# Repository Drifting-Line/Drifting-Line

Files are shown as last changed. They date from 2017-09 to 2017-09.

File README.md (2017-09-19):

# Drifting-Line
The current Mediterranean migratory crisis is causing a large number of deaths at sea: in 2016 more than 5,000 people died trying to reach Europe on board of overcrowded clandestine boats.
The relief panorama has distinct features and connotations: together with government and military naval units, a large number of NGOs has taken the field. International humanitarian treaties on refugees and asylum seekers are very clear and demand that the needs of human beings belonging from countries of war and persecution must be supported in the name of solidarity and common sense of brotherhood. It is time for the Union countries to align with these needs and seek stable and substantial solutions. Meanwhile, this emergency situation requires for the provision of search and rescue measures to avoid the deaths of a large number of desperate and troubled people. The project fits within this area as a concrete support to the existing reliefs network.

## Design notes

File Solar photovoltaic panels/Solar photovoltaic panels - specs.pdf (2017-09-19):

142

I pannelli solari costituiscono una scelta obbligata per quanto riguarda installazioni operative in mare in maniera autonoma e quindi anche nel caso di Drifting-Line.
I modelli da impiegare dovranno essere di piccole dimensioni, leggeri e impermeabili. Il materiale dovrà essere costituito da celle solari amorfe ad alta efficienza, resistenti ai raggi UV e al graffio: il silicio amorfo infatti è più performante in ambienti marittimi rispetto al monocristallino, dove l’umidità e la salsedine rischiano di intaccare maggiormente il materiale. L’attuale facilità di reperimento di tale tecnologia e le possibilità di customizzazione permetteranno di ottenere modelli realizzati assecondando le diverse esigenze e necessità.
Date la vicinanza alle coste nord-africane tali pannelli dovranno essere montati a bordo delle boe con un’inclinazione di 10° (in caso di riutilizzo del progetto in altre posizioni geografiche tale misura dovrà riadattarsi alle diverse latitudini); l’installazione di due pannelli simmetrici rispetto all’asse centrale di sostegno assicurerà maggiore potenza di ricarica ed eviterà, nonostante il peso contenuto, eventuali sbilanciamenti e squilibri.

Caratteristiche principali:
1. Tensione di circuito aperta: 7.7V
2. Tensione di picco: 6.5V
3. Corrente di picco: 340mA
4. Potenza di picco: 2.2W
5. Viti da integrare per un facile montaggio

### 4.2.2.7 Pannelli fotovoltaici

Dimensioni:
customizzabili
Peso:
100g ca.

solar
panels

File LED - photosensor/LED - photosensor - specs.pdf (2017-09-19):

141

In campo marittimo l’illuminazione è un fattore chiave per la sicurezza della navigazione in mare durante le ore notturne o in caso di scarsa visibilità. Come già spiegato precedentemente a bordo di un’imbarcazione ci possono essere vari strumenti che consentono di rilevare la presenza di altri natanti e boe di segnalazione: per esempio radar o tecnologia GPS. Una corretta illuminazione è tuttavia di fondamentale importanza, soprattutto in caso di maltempo o guasti delle strumentazioni di avvistamento.
La tecnologia LED ha consentito un notevole avanzamento per quanto riguarda il consumo della batteria: lasciare accese le luci di posizione per lunghi periodi all’interno di imbarcazioni o altre installazioni in mare non risulta più una preoccupazione come avveniva precedentemente con le lampade tradizionali. Esistono anche altri vantaggi che derivano dall’uso dell’illuminazione LED: tali dispositivi occupano poco spazio e consentono di ottimizzare la progettazione di apparecchi articolati come nel caso di Drifting-Line; in più il ciclo di vita è molto più lungo rispetto a quello delle lampadine tradizionali: ciò permette, in campo nautico e in caso di installazioni in mare, di ridurre al minimo i viaggi a scopo di manutenzione e sostituzione di componenti esauriti.
Per il progetto Drifting-Line verranno utilizzate le strisce LED: idonee per la realizzazione di molti progetti, sono flessibili e dotate di adesivi sul retro che permettono di attaccarle a differenti tipi di supporto. Verranno adoperate strisce impermeabili (ricoperte di silicone), adatte ad essere utlizzate in esterno.

Caratteristiche principali:
1. Alimentazione: DC 12V
2. Consumo per 5m: 72W
3. Luminosità: 6000Lm
4. Durata: 25.000h ca.
5. Temperatura di esercizio: da -20° a +60°
6. Bassissima emissione di calore
7. Altissima flessibilità
8. Striscia divisibile ogni 3 LED
9. Larghezza striscia: 10mm
10. A norma CE RoHS

Il fotosensore (più propriamente detto fotoresistore) è un dispositivo realizzato tramite sostanze sensibili alla luce. Il sensore sarà messo in comunicazione direttamente con il microprocessore di Arduino consentendo così l’accensione dei LED in caso di mancanza di luce, sia durante le ore notturne che in condizioni di maltempo e di scarsa visibilità.
Si tratta di dispositivi molto piccoli e economici: i valori in termini di costi, dimensioni e peso possono essere ritenuti trascurabili all’interno di tutte le voci del progetto.

### 4.2.2.5 Illuminazione LED

### 4.2.2.6 Fotosensore

Dimensioni (per bobina):
in commercio bobine da 5m
Peso (per bobina):
1kg ca.

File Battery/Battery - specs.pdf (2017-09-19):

135

Il litio (spesso abbreviato con Li-Ion) è uno dei principali materiali utilizzati in vari campi dell’elettronica. I vantaggi che derivano dal suo utilizzo nei sistemi di carica sono molteplici: è possibile realizzare batterie molto convenienti ed economiche che possono essere assemblate in diverse forme, raggiungere piccole dimensioni ed essere di gran lunga più leggere di altri modelli realizzati in differenti materiali. Si tratta di batterie in genere poco suscettibili ai cambiamenti di temperatura (per questo vengono largamente utilizzate nel campo della telefonia mobile e dei tablet), una caratteristica determinante per l’inserimento di tale materiale nel progetto in questione: l’esposizione continuata al sole dei dispositivi Drifting-Line ha comportato la scelta di un’alimentazione che non risultasse delicata e che fosse economica da sostituire in caso di anomalie o malfunzionamenti, rendendo così trascurabili alcune sue caratteristiche negative (come, per esempio, il degrado progressivo anche in casi di non utilizzo).

Si stima che la corrente necessaria per il sostentamento del sistema Drifting-Line ammonti a 100Ah: si tratta di un conteggio approssimativo di riferimento; per ottenere un risultato preciso è necessario svolgere dei calcoli per cui è indispensabile conoscere e ricavare, attraverso prove e verifiche, il consumo a riposo e in funzionamento di tutti i componenti del sistema (Arduino + Iridium 9603 + IMSI-Catcher + fotosensore, illuminazione LED), valori impossibili da ottenere a priori.
Un’altra variabile del calcolo di progettazione della batteria è il tempo di autonomia richiesto al dispositivo per funzionare autonomamente. Nel caso di Drifting-Line è stata ipotizzata una vita media di circa un anno e mezzo: si tratta di un buon compromesso temporale per mantenere bassi i volumi e i costi di progettazione della batteria e del sistema di ricarica (che come vedremo nelle pagine successive avviene attraverso tecnologia solare); il progetto non può rappresentare una soluzione duratura, infatti nel caso più specifico del fenomeno della crisi umanitaria si spera che un anno e mezzo possa corrispondere a un periodo di miglioramenti e cambiamenti in campo politico e governativo.

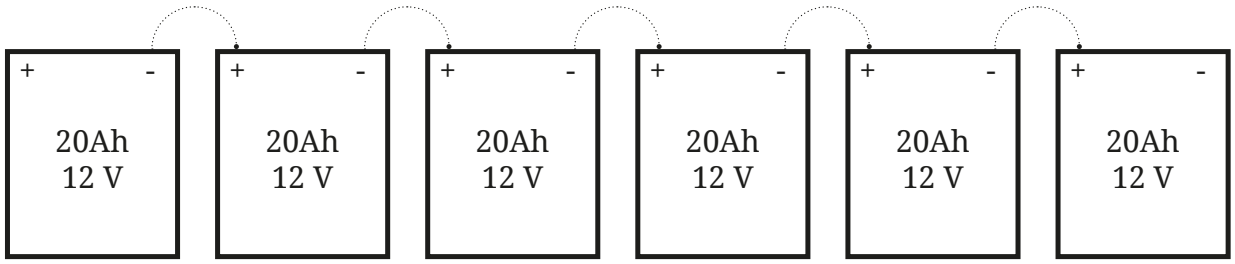
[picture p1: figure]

Il progetto prevede dunque l’utilizzo in serie di sei pack di batterie al litio da 20Ah ciascuna, in modo tale da garantire e superare il valore minimo definito precedentemente a 100Ah. In caso di anomalie e irregolarità un sistema ridondante può risultare favorevole: l’aumento e la suddivisione delle componenti di carica permette di accrescere l’affidabilità e la disponibilità durante tutto il tempo di funzionamento.

### 4.2.2.1 Batterie al litio 12v 20Ah

Dimensioni (per unità):
customizzabili
Peso (per unità):
2kg ca.

Progetto scaricabile da Github

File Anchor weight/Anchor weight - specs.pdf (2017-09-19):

146

La misurazione dell’ancoraggio prevede un calcolo specifico in cui le varibili di riferimento sono le forze dovute al vento e alle correnti.

Forze dovute al vento (FV)
Fv= 0,0128 · V² (nodi) · K
K= 1,3
Fv= 0,0128 · 60²
- 1,3= 60kgf/m²
Se si moltiplica tale risultato per il valore della superficie esterna della boa (S1

) si otteniene la misura delle forze di attrito del vento che incidono sulla boa stessa, ovvero:
FV= Fv (kgf/m²

) · S1 (m²

)
FV= 60 · 2,1= 126kgf

Forze dovute alle correnti (Fc)
Si dividono in due componenti: (Pd + Pf)
1. Pd è la spinta dinamica della corrente che investe la proiezione verticale della parte sommersa della boa:
Pd= 2,86 · Kd · S2 (m²

) · c²
Kd= 0,75 - 1
Pd= 2,86 · 1 · 1,8 · 0,6²

= 1,8kgf

2. Pf è la resistenza di attrito: Pf= Kf · S2 (m²

) · c²
Kf= 0,01
Pf= 0,01 · 1,8 · 0,6²

= 0,006kgf

Forze totali (Ftot)
Ftot= Fv + Fc
Ftot= 126 + 1,8 + 0,006= 127,8kgf

Il risultato ottenuto corrisponde alle somma delle forze che insistono sulla struttura di ciascuna boa. Il peso in acqua del carico che verrà gettato come ancoraggio sul fondale dovrà avere un valore maggiore per riuscire a contrastare in maniera efficace le spinte esterne.
Il progetto Drifting-Line prevede di utilizzare tre o più gabbie metalliche in acciaio zincato da riempire di materiale inerte (nel caso specifico tre gabbie metalliche da 40/50kg ciascuna) e collegate alla cima principale tramite altri tre segmenti di Dyneema® SK78 lunghi cinque metri ciascuno. Si potrà utilizzare calcestruzzo o semilavorati in metallo, pietre o materiale dismesso di qualsiasi genere; tutti i carichi gettati in acqua tuttavia perdono parte della loro forza peso ed è bene specificare già da subito che a parità di volume il metallo è l’elemento più adatto per queste condizioni.

## 4.2.5 Ancoraggio

Dati di partenza:
1. Velocità massima del vento (V): 60nodi
2. Superficie esterna di attrito della boa (S1

): 2,1m²
3. Velocità della corrente
(c): 0,6nodi
4. Superficie immersa di attrito della boa (S2

): 1,8m²

↑ Percentuale di peso
perso dai materiali in
acqua.

Valori dei pesi in → acqua di calcestruzzo

e acciaio, i materiali
di ancoraggio più
comunemente utilizzati.

Calcestruzzo
45%

Peso ancora

230kg
138kg
92kg
46kg
23kg
13kg

Csl

126kg
75kg
50kg
25kg
12kg
7kg

Acciaio

194kg
116kg
77kg
38kg
19kg
11kg

Granito
36%

Ferro
14%

Acciaio
13%

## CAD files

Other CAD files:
3D print components/#3D print.3dm

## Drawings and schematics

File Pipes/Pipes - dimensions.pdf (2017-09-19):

1

2

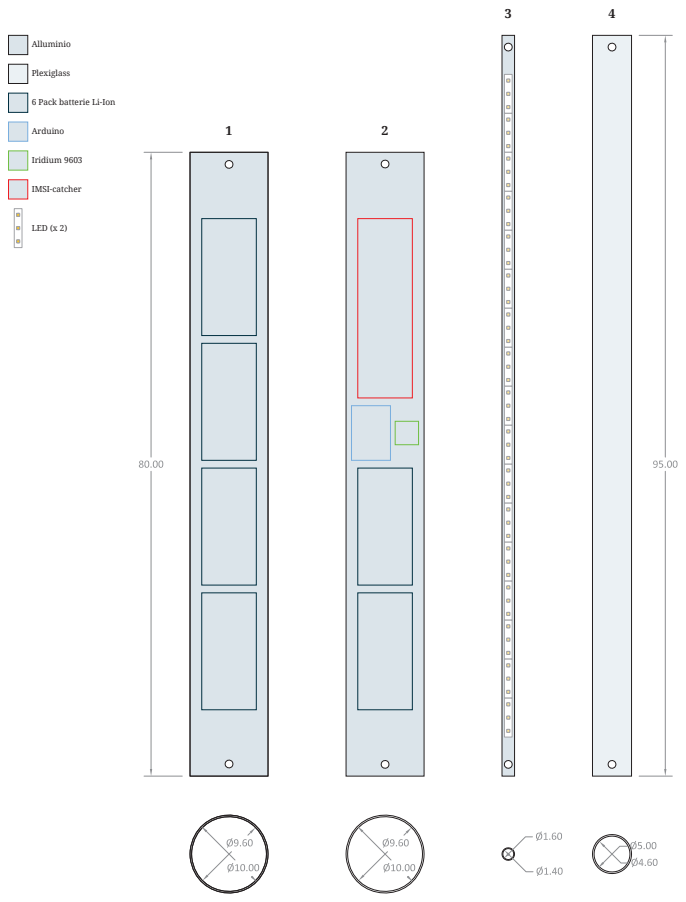
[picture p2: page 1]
Alluminio; Plexiglass; Arduino; Iridium 9603; IMSI-catcher; LED (x 2)

6 Pack batterie Li-Ion

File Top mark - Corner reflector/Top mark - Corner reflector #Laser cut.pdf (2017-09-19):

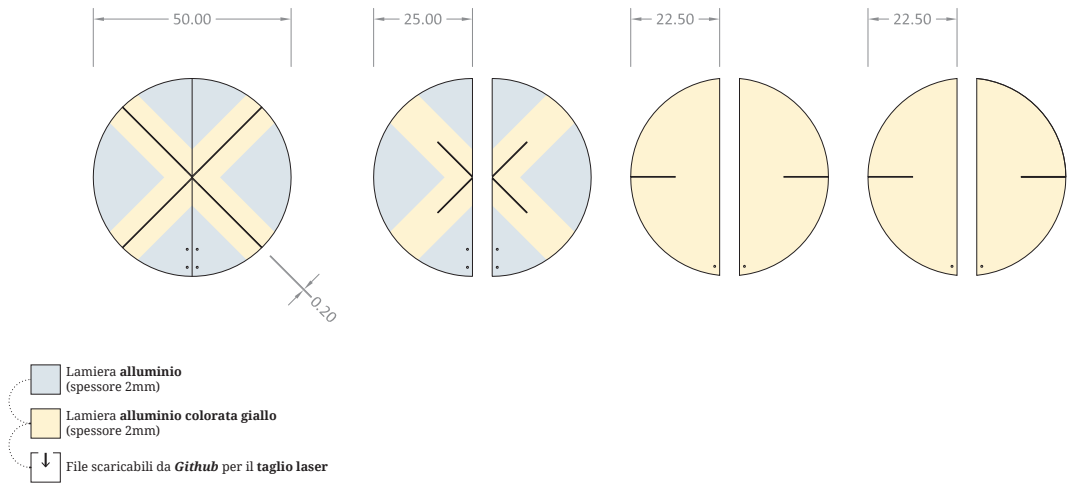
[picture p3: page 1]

Lamiera alluminio
(spessore 2mm)
Lamiera alluminio colorata giallo

File scaricabili da Github per il taglio laser

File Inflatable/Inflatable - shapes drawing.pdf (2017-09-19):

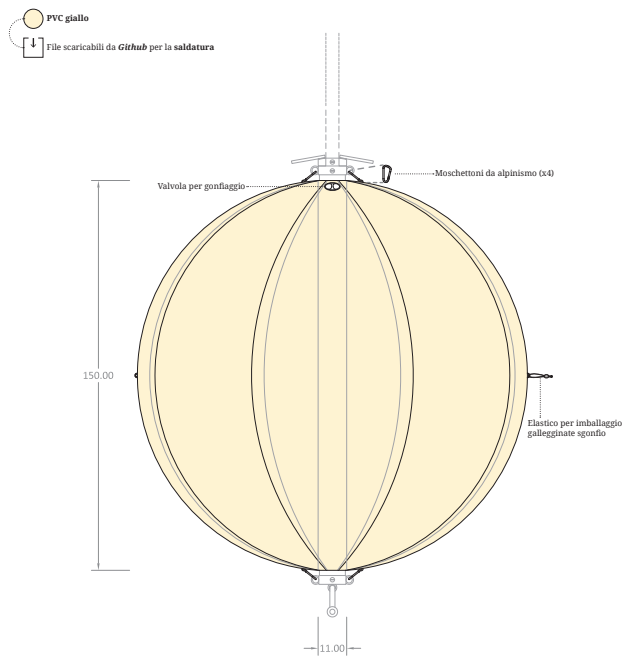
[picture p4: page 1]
PVC giallo

File scaricabili da Github per la saldatura

Moschettoni da alpinismo (x4)

Valvola per gonfiaggio

Elastico per imballaggio
gallegginate sgonfio

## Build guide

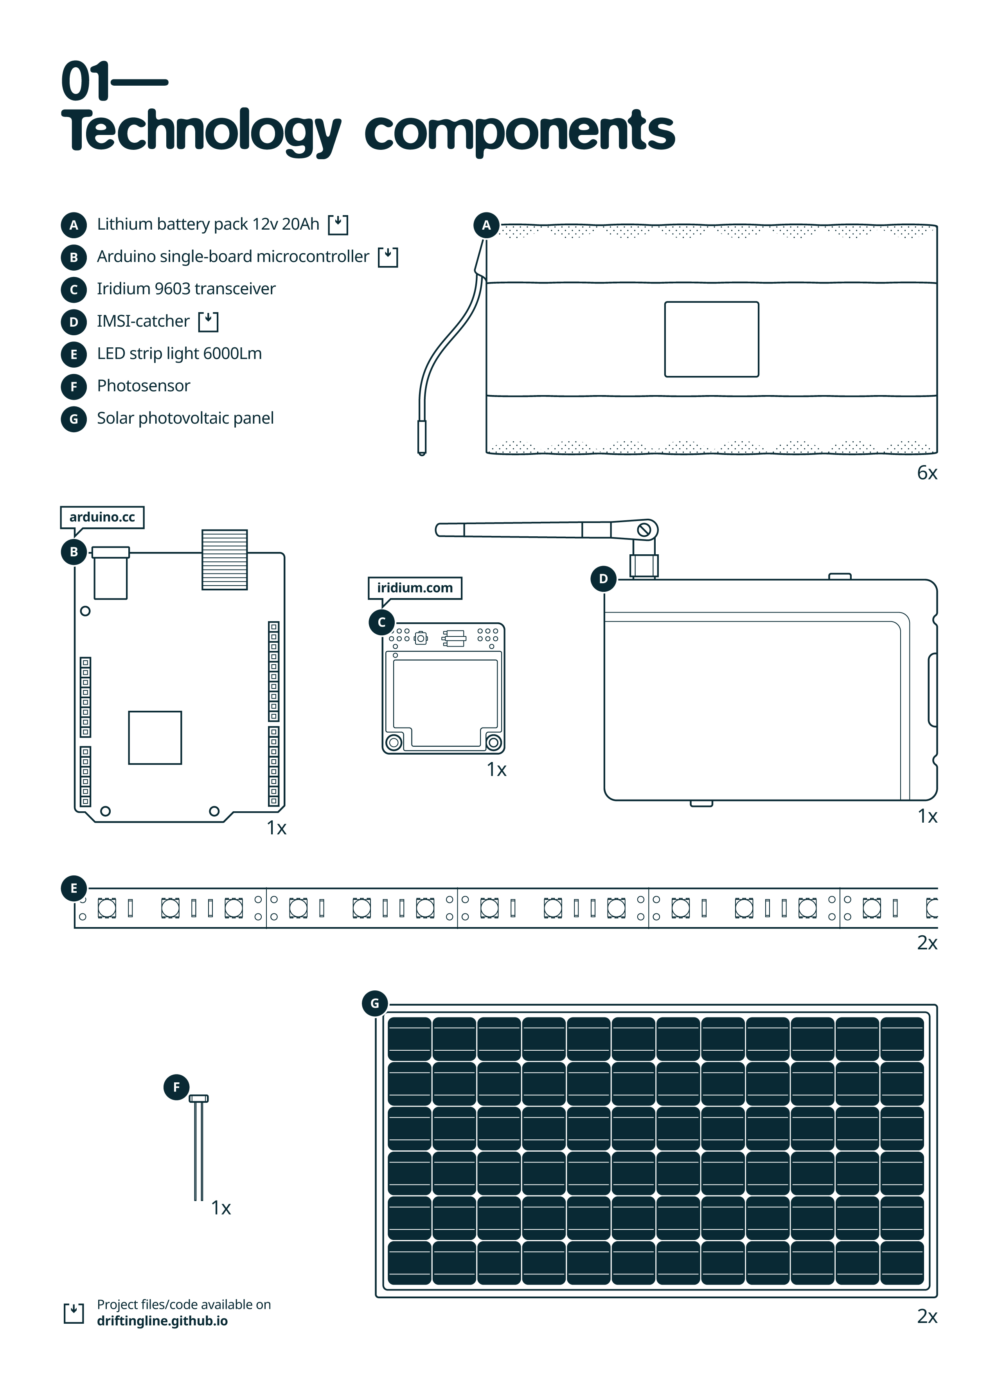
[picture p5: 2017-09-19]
--- Instruction Manual ---/manual03-02.jpg

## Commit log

2017-09-19 Arduino code
2017-09-19 Lithium battery pack
2017-09-19 Top mark - Corner reflector - Laser cut
2017-09-19 Top mark - Corner reflector #Laser cut
2017-09-19 3D print
    [3D components.3dm]
2017-09-19 #3D components
    [#3D components.3dm]
2017-09-19 #3D print
    [#3D print.3dm]
2017-09-19 LED strip
2017-09-19 Battery - specs
2017-09-19 LED strip - specs
2017-09-19 Cable - specs
2017-09-19 LED - photosensor - specs
